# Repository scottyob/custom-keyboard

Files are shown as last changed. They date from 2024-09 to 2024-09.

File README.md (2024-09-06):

# custom-keyboard
My very first custom keyboard!

## Goals
* Be really quick to change machines from a work computer, personal computer, and embedded computer
* Have an embeded display for e-mails and custom notifications.

## Designing
[Keyboard Layout Editor](http://www.keyboard-layout-editor.com/) is used to build the layout
[PCB Generator](https://builder.mrkeebs.com/) is used to build the base KiCad templates - Not working
[KiCad plugin](https://github.com/adamws/kicad-kbplacer) Maybe this

## Inspiration
https://github.com/overlordpro-sys/keycool84keyboard
[Designers Guide](https://wiki.ai03.com/books/pcb-design/chapter/pcb-designer-guide)
[Great YouTube Design](https://www.youtube.com/watch?v=8WXpGTIbxlQ) (plus, his name is Scotto!)

## Display options
* This looks small enough and has a large enough resolution to be useful:  https://www.amazon.com/Portable-Computer-Temperature-Raspberry-Monitoring/dp/B0C5CJSM3B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

## Log
The KeyCool 84 model was used

## BOM
Keys:  https://www.amazon.com/Ranked-Ks-33-Switches-Mechanical-Keyboards/dp/B09WYFZ9RW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

Switches:  Keychron Low-Profile Keychron Optical White Switch Set:  https://www.amazon.com/Keychron-Low-Profile-Optical-White-Switch/dp/B09F8N5671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

---
Keys:  https://nuphy.com/products/nuphy-wisteria-t55-low-profile-switches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

[200~NuPhy Wisteria Low-profile Switches

**You'll want Gateron KS-33**

Use These:  https://shop.beekeeb.com/product/gateron-low-profile-hotswap-socket/
With this footprint:  https://github.com/siderakb/key-switches.pretty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

Guides:
https://github.com/ebastler/zmk-designguide
this recommends holyiot 18010 or moko mk08a. other people fiddle around with stuff like xiao nrf or even nice!nano (or nice!nano clones)

Keycaps perhaps:
- These are not shine through, but I like them!  https://www.amazon.com/Chocfox-Keyboard-Switches-Mechanical-white-134Keys/dp/B0CQ1ZHDP8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

- Yeah, I think these keycaps:  https://www.amazon.com/XVX-Profile-Keyboard-Switches-Mechanical/dp/B0BVYV67QS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

 - Controller

Probably this:  https://makerdiary.com/products/nrf52840-connectkit?variant=43255093035163

# Setup
1. Install [This Plugin](https://github.com/ebastler/marbastlib)
2. 

Footprint for KS-33:  https://shop.beekeeb.com/product/gateron-low-profile-hotswap-socket/

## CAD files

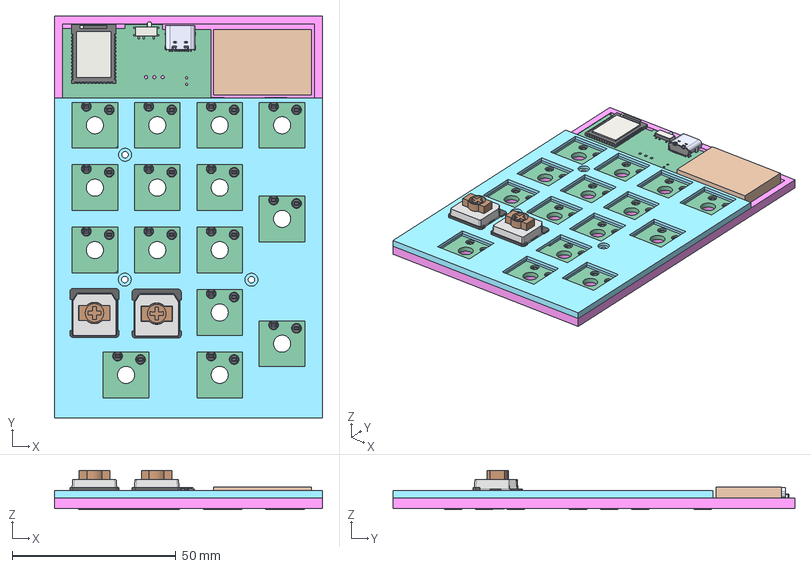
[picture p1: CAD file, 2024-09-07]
Schema/Keypad/Enclosure.FCStd
81.9 x 122.7 x 11.9 mm
f0684a6a-028c-11ee-ae0e-34c93d8226b1_part
f06a1f0c-028c-11ee-ae0e-34c93d8226b1_part
f1cc5b76-028c-11ee-ae0e-34c93d8226b1_part
f1cc5d06-028c-11ee-ae0e-34c93d8226b1_part
f1cc5d92-028c-11ee-ae0e-34c93d8226b1_part
f1cc5d92-028c-11ee-ae0e-34c93d8226b1_part001
f0684a6a-028c-11ee-ae0e-34c93d8226b1_part001
f06a1f0c-028c-11ee-ae0e-34c93d8226b1_part001
f1cc5b76-028c-11ee-ae0e-34c93d8226b1_part001
f1cc5d06-028c-11ee-ae0e-34c93d8226b1_part001
f1cc5d92-028c-11ee-ae0e-34c93d8226b1_part003
f1cc5d92-028c-11ee-ae0e-34c93d8226b1_part004
Pcb_ee0a
TYPE-C-31-M-12
TYPE-C-31-M-013
TYPE-C-31-M-014
TYPE-C-31-M-015
TYPE-C-31-M-016
TYPE-C-31-M-017
TYPE-C-31-M-018
TYPE-C-31-M-019
TYPE-C-31-M-020
TYPE-C-31-M-021
TYPE-C-31-M-022
TYPE-C-31-M-023
TYPE-C-31-M-024
TYPE-C-31-M-025
TYPE-C-31-M-026
TYPE-C-31-M-027
TYPE-C-31-M-028
TYPE-C-31-M-029
TYPE-C-31-M-030
TYPE-C-31-M-031
TYPE-C-31-M-032
TYPE-C-31-M-033
TYPE-C-31-M-034
TYPE-C-31-M-035
TYPE-C-31-M-036
TYPE-C-31-M-037
TYPE-C-31-M-038
TYPE-C-31-M-039
TYPE-C-31-M-040
TYPE-C-31-M-041
TYPE-C-31-M-042
TYPE-C-31-M-043
TYPE-C-31-M-044
TYPE-C-31-M-045
TYPE-C-31-M-046
TYPE-C-31-M-047
TYPE-C-31-M-048
TYPE-C-31-M-049
TYPE-C-31-M-050
TYPE-C-31-M-051
TYPE-C-31-M-052
TYPE-C-31-M-053
MSK12C02 v4
MSK12C02 v005
MSK12C02 v006
MSK12C02 v007
MSK12C02 v008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

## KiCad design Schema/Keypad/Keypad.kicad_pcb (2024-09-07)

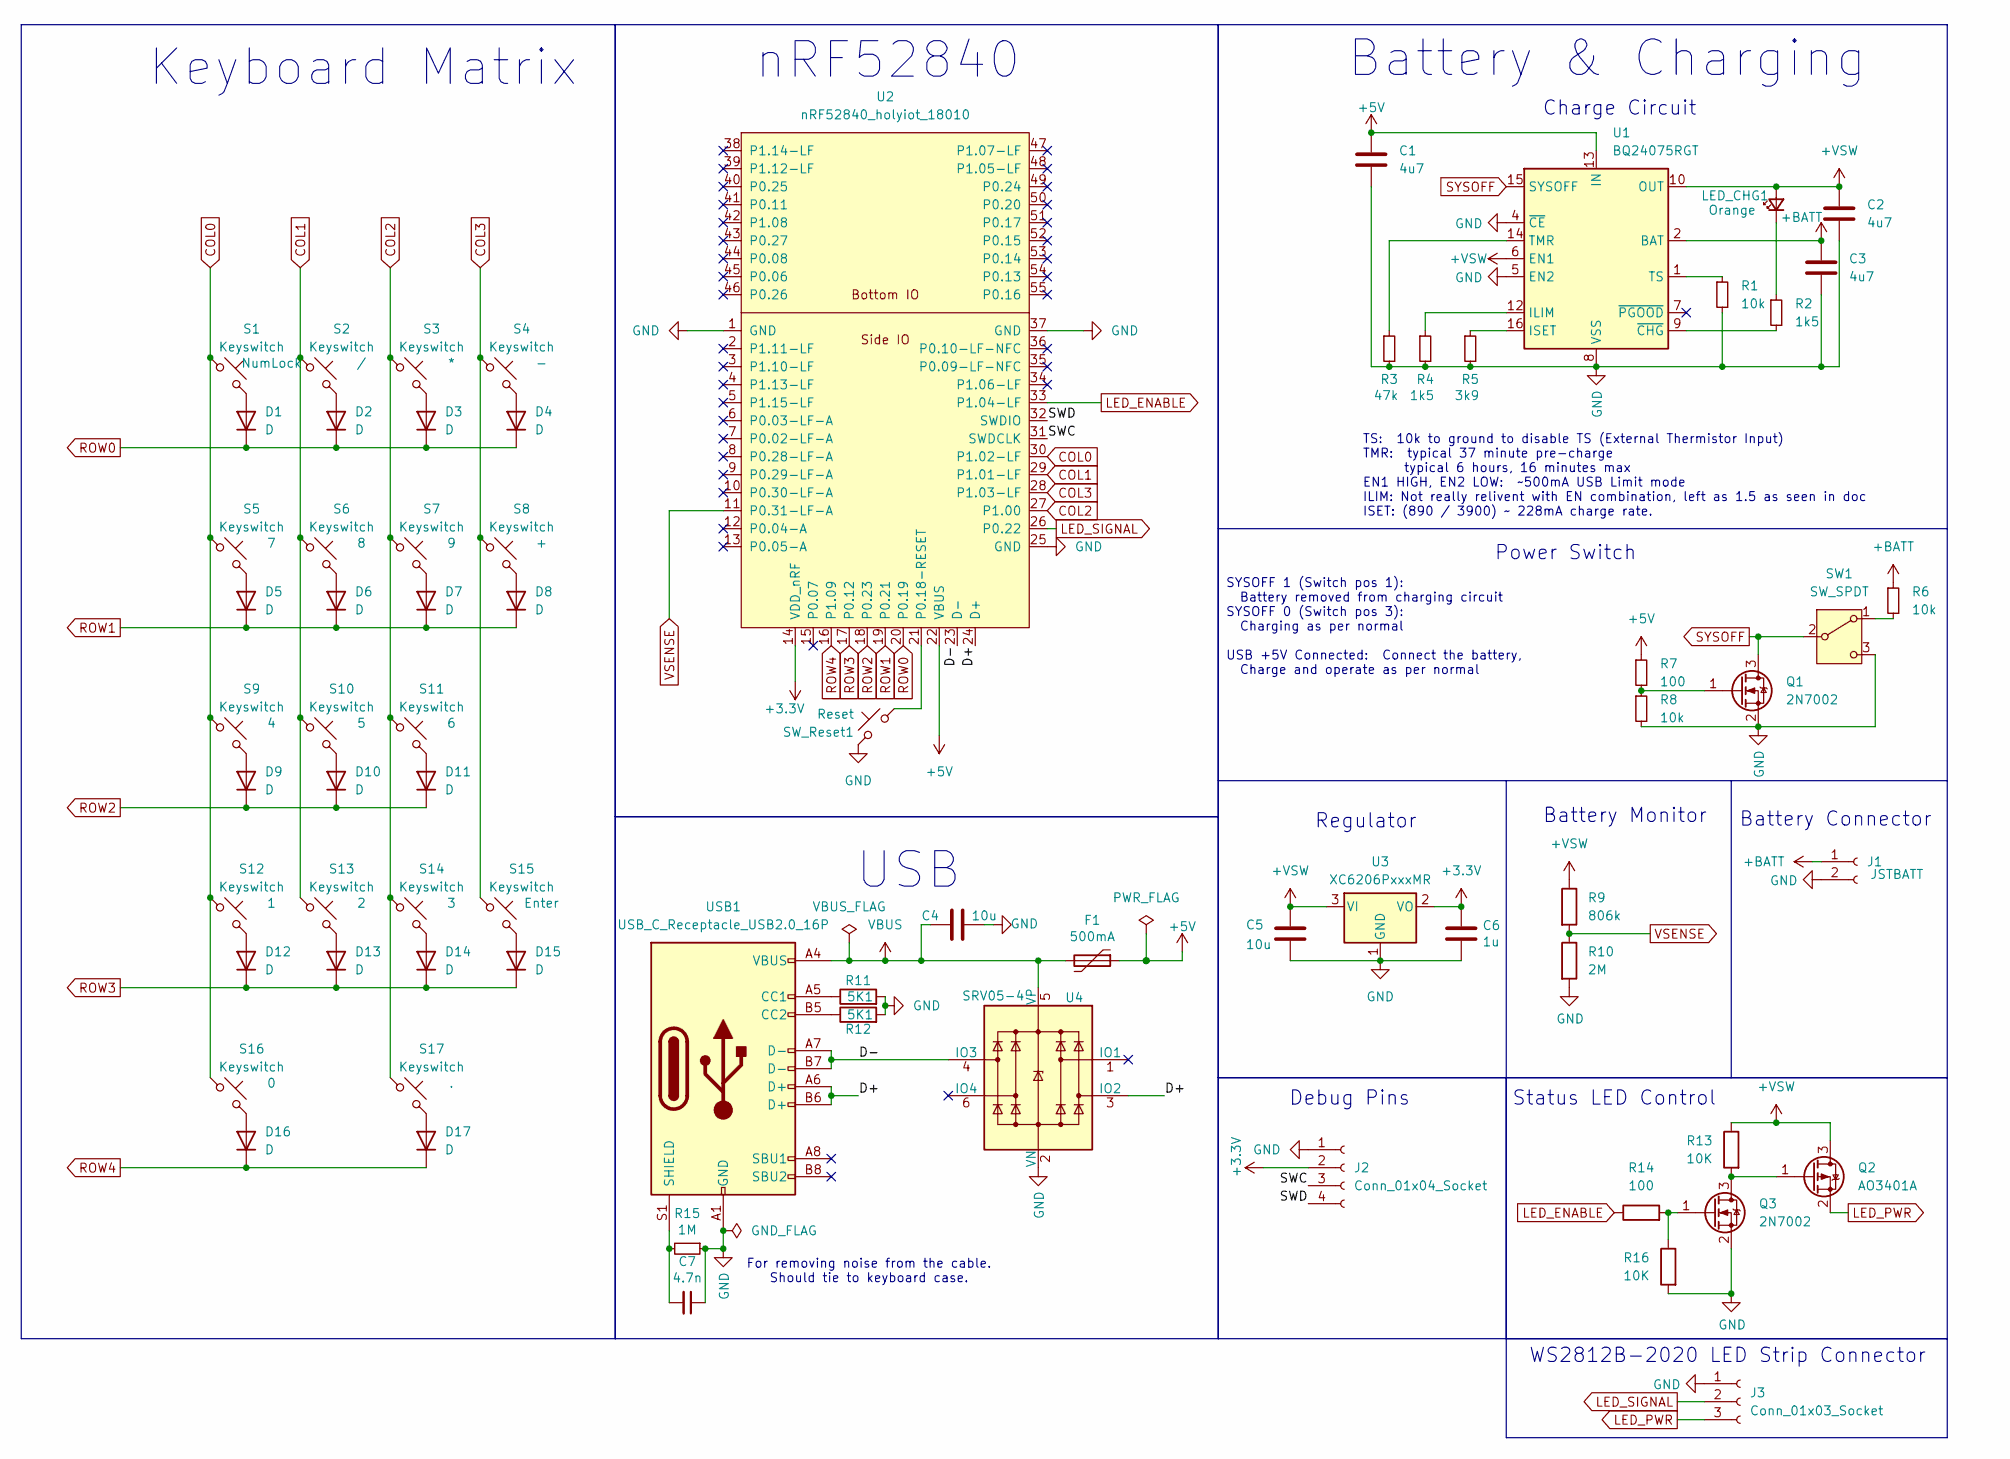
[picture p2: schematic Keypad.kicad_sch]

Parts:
C1, C2, C3: 4u7; C_0603_1608Metric
C4, C5: 10u; C_0603_1608Metric; MPN CL10A106KP8NNNC; JLCSMT C19702
C6: 1u; C_0603_1608Metric; MPN CL10A105KB8NNNC; LCSC C15849
C7: 4.7n; C_0805_2012Metric
D1, D2, D3, D4, D5, D6, D7, D8, D9, D10, D11, D12, D13, D14, D15, D16, D17: D; Diode_SOD-123
F1: 500mA; Fuse_0805_2012Metric; MPN SMD0805-050; JLCSMT C66452
J1: JSTBATT; JST_PH_S2B-PH-K_1x02_P2.00mm_Horizontal
J2: Conn_01x04_Socket; PinHeader_1x04_P2.54mm_Vertical
J3: Conn_01x03_Socket; PinSocket_1x03_P2.54mm_Vertical
LED_CHG1: Orange; LED_0603_1608Metric_Pad1.05x0.95mm_HandSolder
Q1, Q3: 2N7002; SOT-23
Q2: AO3401A; SOT-23
R1, R6, R8: 10k; R_0603_1608Metric_Pad0.98x0.95mm_HandSolder
R2, R4: 1k5; R_0603_1608Metric_Pad0.98x0.95mm_HandSolder
R3: 47k; R_0603_1608Metric_Pad0.98x0.95mm_HandSolder
R5: 3k9; R_0603_1608Metric_Pad0.98x0.95mm_HandSolder
R7, R14: 100; R_0603_1608Metric_Pad0.98x0.95mm_HandSolder
R9: 806k; R_0603_1608Metric_Pad0.98x0.95mm_HandSolder
R10: 2M; R_0603_1608Metric_Pad0.98x0.95mm_HandSolder
R11, R12: 5K1; R_0603_1608Metric_Pad0.98x0.95mm_HandSolder
R13, R16: 10K; R_0603_1608Metric_Pad0.98x0.95mm_HandSolder
R15: 1M; R_0603_1608Metric_Pad0.98x0.95mm_HandSolder
S1, S2, S3, S4, S5, S6, S7, S8, S9, S10, S11, S12, S13, S14, S15, S16, S17: Keyswitch; SW_KS33_HS_KS-2P02B01-02_HS_1u
SW1: SW_SPDT; SW_MSK12C02-HB
SW_Reset1: Reset; SW_Push_1P1T_NO_6x6mm_H9.5mm
U1: BQ24075RGT; VQFN-16-1EP_3x3mm_P0.5mm_EP1.6x1.6mm
U2: nRF52840_holyiot_18010
U3: XC6206PxxxMR; SOT-23-3
U4: SRV05-4; SOT-23-6; MPN SRV05-4-P-T7; JLCSMT C85364
USB1: USB_C_Receptacle_USB2.0_16P; USB_C_Receptacle_HRO_TYPE-C-31-M-12

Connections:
+3.3V: C6.2, J2.2, U2.14 (VDD_nRF), U3.2 (VO)
+5V: C1.1, F1.1, R7.1, U1.13 (IN), U2.22 (VBUS)
+BATT: C3.1, J1.1, R6.1, U1.2 (BAT), U1.3 (BAT)
+VSW: C2.1, C5.1, LED_CHG1.2 (A), Q2.3 (D), R9.1, R13.1, U1.6 (EN1), U1.10 (OUT), U1.11 (OUT), U3.3 (VI)
/D+: U2.24 (D+), U4.3 (IO2), USB1.A6 (D+), USB1.B6 (D+)
/D-: U2.23 (D-), U4.4 (IO3), USB1.A7 (D-), USB1.B7 (D-)
/SWC: J2.3, U2.31 (SWDCLK)
/SWD: J2.4, U2.32 (SWDIO)
COL0: S1.1, S5.1, S9.1, S12.1, S16.1, U2.30 (P1.02-LF)
COL1: S2.1, S6.1, S10.1, S13.1, U2.29 (P1.01-LF)
COL2: S3.1, S7.1, S11.1, S14.1, S17.1, U2.27 (P1.00)
COL3: S4.1, S8.1, S15.1, U2.28 (P1.03-LF)
GND: C1.2, C2.2, C3.2, C4.1, C5.2, C6.1, C7.1, J1.2, J2.1, J3.1, Q1.2 (S), Q3.2 (S), R1.2, R3.2, R4.2, R5.2, R8.2, R10.2, R11.2, R12.2, R15.1, R16.2, SW1.3 (C), SW_Reset1.1, U1.4 (~CE), U1.5 (EN2), U1.8 (VSS), U1.17 (VSS), U2.1 (GND), U2.25 (GND), U2.37 (GND), U3.1 (GND), U4.2 (VN), USB1.A1 (GND), USB1.A12 (GND), USB1.B1 (GND), USB1.B12 (GND)
LED_ENABLE: R14.1, U2.33 (P1.04-LF)
LED_PWR: J3.3, Q2.2 (S)
LED_SIGNAL: J3.2, U2.26 (P0.22)
unnamed: D1.2 (A), S1.2
unnamed: D2.2 (A), S2.2
unnamed: D3.2 (A), S3.2
unnamed: D4.2 (A), S4.2
unnamed: D5.2 (A), S5.2
unnamed: D6.2 (A), S6.2
unnamed: D7.2 (A), S7.2
unnamed: D8.2 (A), S8.2
unnamed: D9.2 (A), S9.2
unnamed: D10.2 (A), S10.2
unnamed: D11.2 (A), S11.2
unnamed: D12.2 (A), S12.2
unnamed: D13.2 (A), S13.2
unnamed: D14.2 (A), S14.2
unnamed: D15.2 (A), S15.2
unnamed: D16.2 (A), S16.2
unnamed: D17.2 (A), S17.2
unnamed: LED_CHG1.1 (K), R2.1
unnamed: Q1.1 (G), R7.2, R8.1
unnamed: Q2.1 (G), Q3.3 (D), R13.2
unnamed: Q3.1 (G), R14.2, R16.1
unnamed: R6.2, SW1.1 (A)
unnamed: R4.1, U1.12 (ILIM)
unnamed: R5.1, U1.16 (ISET)
unnamed: R3.1, U1.14 (TMR)
unnamed: R1.1, U1.1 (TS)
unnamed: R2.2, U1.9 (~CHG)
unnamed: SW_Reset1.2, U2.21 (P0.18-RESET)
unnamed: R11.1, USB1.A5 (CC1)
unnamed: R12.1, USB1.B5 (CC2)
unnamed: C7.2, R15.2, USB1.S1 (SHIELD)
ROW0: D1.1 (K), D2.1 (K), D3.1 (K), D4.1 (K), U2.20 (P0.19)
ROW1: D5.1 (K), D6.1 (K), D7.1 (K), D8.1 (K), U2.19 (P0.21)
ROW2: D9.1 (K), D10.1 (K), D11.1 (K), U2.18 (P0.23)
ROW3: D12.1 (K), D13.1 (K), D14.1 (K), D15.1 (K), U2.17 (P0.12)
ROW4: D16.1 (K), D17.1 (K), U2.16 (P1.09)
SYSOFF: Q1.3 (D), SW1.2 (B), U1.15 (SYSOFF)
VBUS: C4.2, F1.2, U4.5 (VP), USB1.A4 (VBUS), USB1.A9 (VBUS), USB1.B4 (VBUS), USB1.B9 (VBUS)
VSENSE: R9.2, R10.1, U2.11 (P0.31-LF-A)

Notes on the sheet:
Status LED Control
WS2812B-2020 LED Strip Connector
USB
Battery & Charging
nRF52840
Charge Circuit
Battery Connector
Power Switch
Keyboard Matrix
SYSOFF 1 (Switch pos 1): Battery removed from charging circuit SYSOFF 0 (Switch pos 3): Charging as per normal USB +5V Connected: Connect the battery, Charge and operate as per normal
Debug Pins
For removing noise from the cable. Should tie to keyboard case.
Battery Monitor
Regulator
TS: 10k to ground to disable TS (External Thermistor Input) TMR: typical 37 minute pre-charge typical 6 hours, 16 minutes max EN1 HIGH, EN2 LOW: ~500mA USB Limit mode ILIM: Not really relivent with EN combination, left as 1.5 as seen in doc ISET: (890 / 3900) ~ 228mA charge rate.

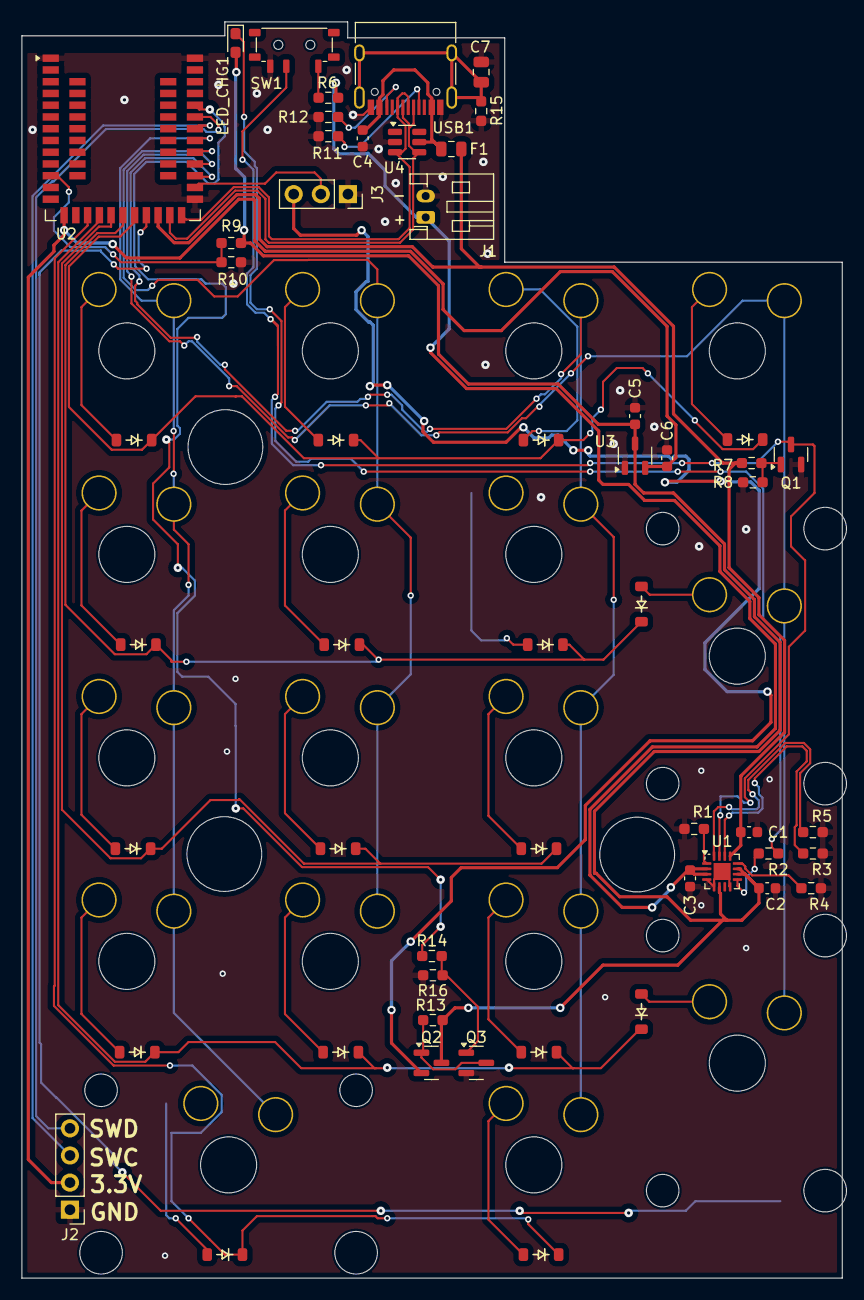
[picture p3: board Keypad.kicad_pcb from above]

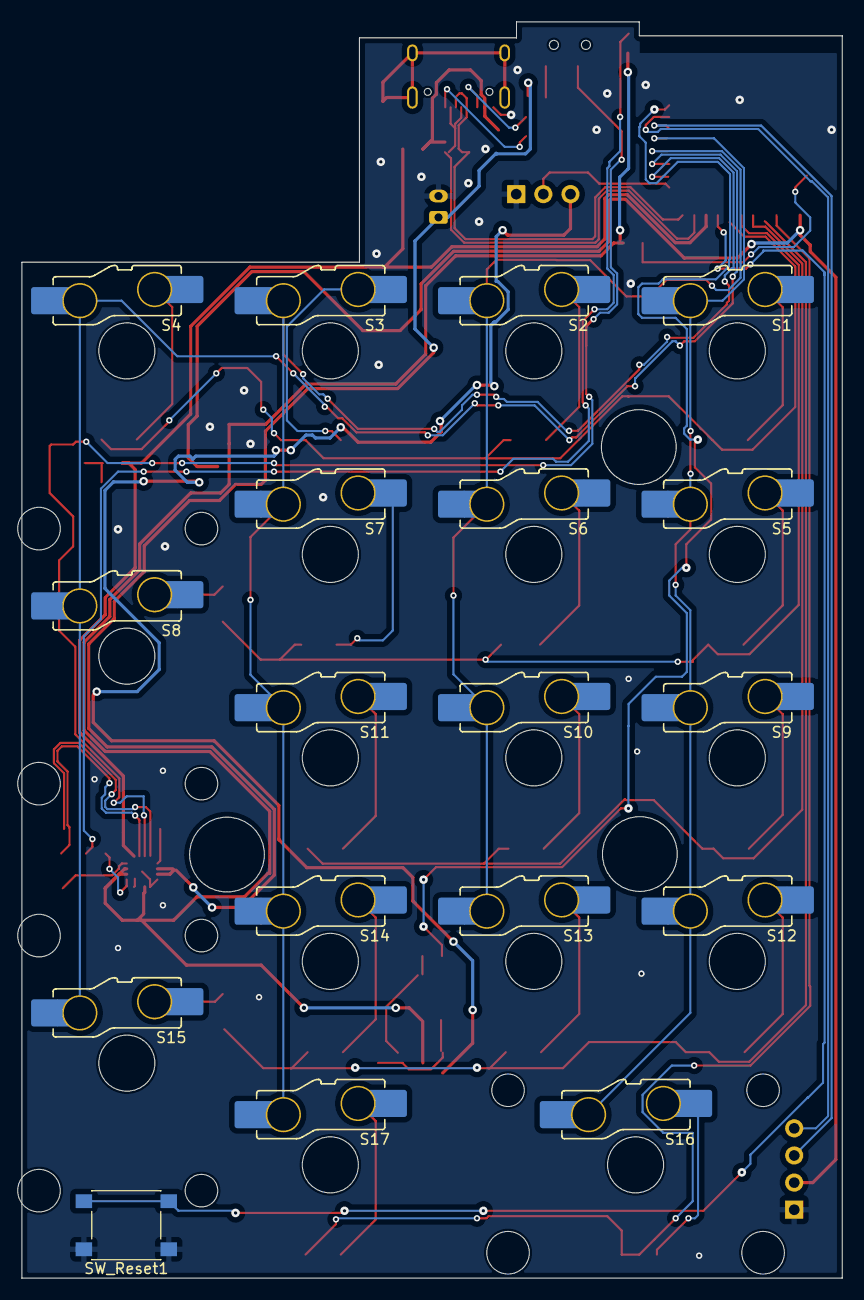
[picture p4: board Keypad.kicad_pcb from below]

Board: 2 copper layers, 76.8 x 117.6 mm, 72 parts (18 on the bottom side), 55 nets.

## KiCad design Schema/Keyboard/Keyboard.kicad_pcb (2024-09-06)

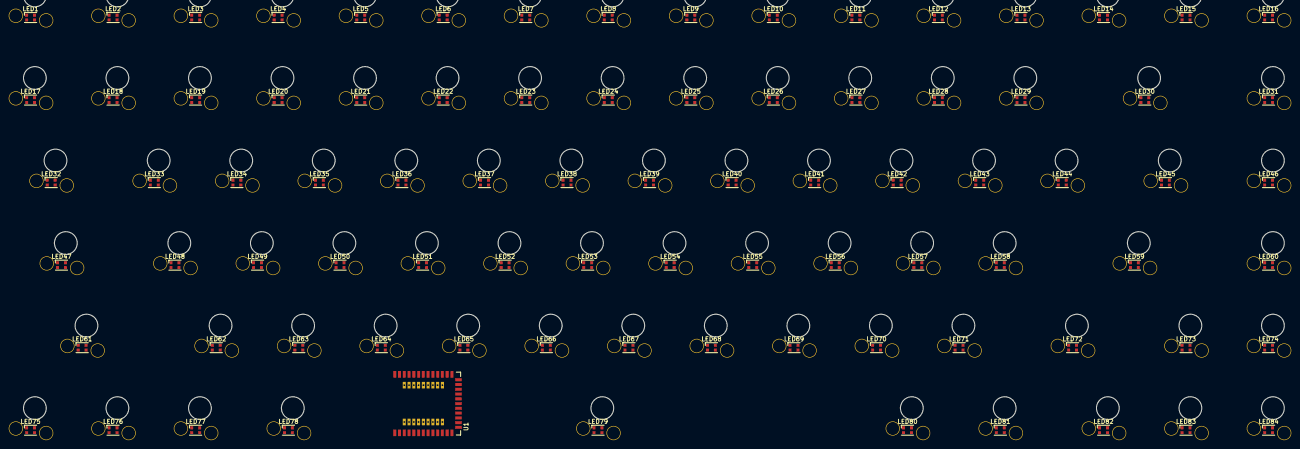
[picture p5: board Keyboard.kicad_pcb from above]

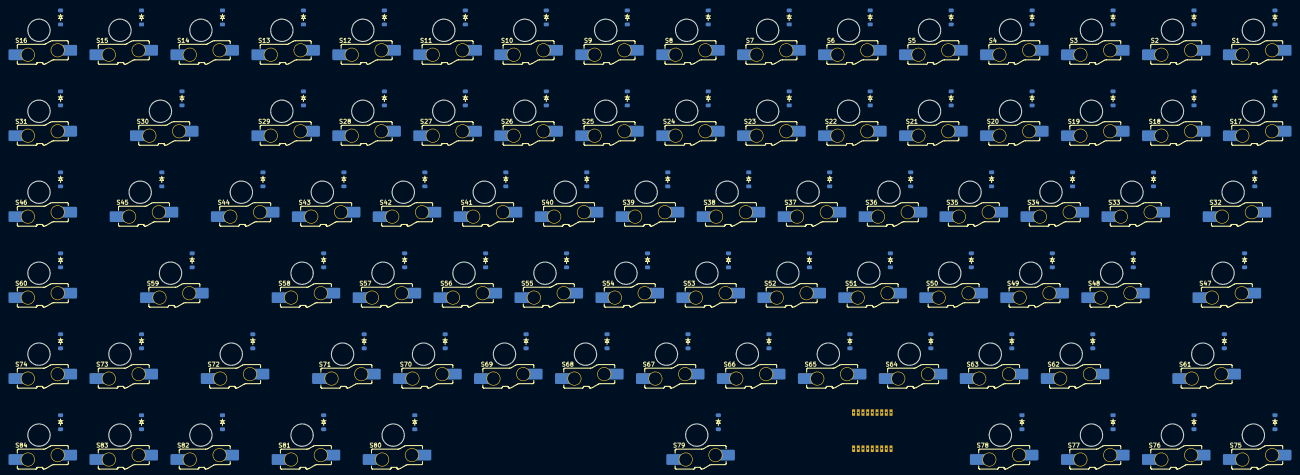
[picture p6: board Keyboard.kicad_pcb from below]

Board: 2 copper layers, 253 parts (168 on the bottom side), 191 nets, no tracks yet.

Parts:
D1, D2, D3, D4, D5, D6, D7, D8, D9, D10, D11, D12, D13, D14, D15, D16, D17, D18, D19, D20, D21, D22, D23, D24, D25, D26, D27, D28, D29, D30, D31, D32, D33, D34, D35, D36, D37, D38, D39, D40, D41, D42, D43, D44, D45, D46, D47, D48, D49, D50, D51, D52, D53, D54, D55, D56, D57, D58, D59, D60, D61, D62, D63, D64, D65, D66, D67, D68, D69, D70, D71, D72, D73, D74, D75, D76, D77, D78, D79, D80, D81, D82, D83, D84: D; Diode_SOD-123
LED1, LED2, LED3, LED4, LED5, LED6, LED7, LED8, LED9, LED10, LED11, LED12, LED13, LED14, LED15, LED16, LED17, LED18, LED19, LED20, LED21, LED22, LED23, LED24, LED25, LED26, LED27, LED28, LED29, LED30, LED31, LED32, LED33, LED34, LED35, LED36, LED37, LED38, LED39, LED40, LED41, LED42, LED43, LED44, LED45, LED46, LED47, LED48, LED49, LED50, LED51, LED52, LED53, LED54, LED55, LED56, LED57, LED58, LED59, LED60, LED61, LED62, LED63, LED64, LED65, LED66, LED67, LED68, LED69, LED70, LED71, LED72, LED73, LED74, LED75, LED76, LED77, LED78, LED79, LED80, LED81, LED82, LED83, LED84: WS2812B-2020; LED_WS2812B-2020_PLCC4_2.0x2.0mm
S1, S2, S3, S4, S5, S6, S7, S8, S9, S10, S11, S12, S13, S14, S15, S16, S17, S18, S19, S20, S21, S22, S23, S24, S25, S26, S27, S28, S29, S30, S31, S32, S33, S34, S35, S36, S37, S38, S39, S40, S41, S42, S43, S44, S45, S46, S47, S48, S49, S50, S51, S52, S53, S54, S55, S56, S57, S58, S59, S60, S61, S62, S63, S64, S65, S66, S67, S68, S69, S70, S71, S72, S73, S74, S75, S76, S77, S78, S79, S80, S81, S82, S83, S84: Keyswitch; SW_KS33_HS_KS-2P02B01-02_HS_1u
U1: nRF52840_holyiot_18010

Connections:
+5V: LED1.4 (VDD), LED2.4 (VDD), LED3.4 (VDD), LED4.4 (VDD), LED5.4 (VDD), LED6.4 (VDD), LED7.4 (VDD), LED8.4 (VDD), LED9.4 (VDD), LED10.4 (VDD), LED11.4 (VDD), LED12.4 (VDD), LED13.4 (VDD), LED14.4 (VDD), LED15.4 (VDD), LED16.4 (VDD), LED17.4 (VDD), LED18.4 (VDD), LED19.4 (VDD), LED20.4 (VDD), LED21.4 (VDD), LED22.4 (VDD), LED23.4 (VDD), LED24.4 (VDD), LED25.4 (VDD), LED26.4 (VDD), LED27.4 (VDD), LED28.4 (VDD), LED29.4 (VDD), LED30.4 (VDD), LED31.4 (VDD), LED32.4 (VDD), LED33.4 (VDD), LED34.4 (VDD), LED35.4 (VDD), LED36.4 (VDD), LED37.4 (VDD), LED38.4 (VDD), LED39.4 (VDD), LED40.4 (VDD), LED41.4 (VDD), LED42.4 (VDD), LED43.4 (VDD), LED44.4 (VDD), LED45.4 (VDD), LED46.4 (VDD), LED47.4 (VDD), LED48.4 (VDD), LED49.4 (VDD), LED50.4 (VDD), LED51.4 (VDD), LED52.4 (VDD), LED53.4 (VDD), LED54.4 (VDD), LED55.4 (VDD), LED56.4 (VDD), LED57.4 (VDD), LED58.4 (VDD), LED59.4 (VDD), LED60.4 (VDD), LED61.4 (VDD), LED62.4 (VDD), LED63.4 (VDD), LED64.4 (VDD), LED65.4 (VDD), LED66.4 (VDD), LED67.4 (VDD), LED68.4 (VDD), LED69.4 (VDD), LED70.4 (VDD), LED71.4 (VDD), LED72.4 (VDD), LED73.4 (VDD), LED74.4 (VDD), LED75.4 (VDD), LED76.4 (VDD), LED77.4 (VDD), LED78.4 (VDD), LED79.4 (VDD), LED80.4 (VDD), LED81.4 (VDD), LED82.4 (VDD), LED83.4 (VDD), LED84.4 (VDD)
COL0: S1.1, S17.1, S32.1, S47.1, S75.1
COL1: S2.1, S18.1, S61.1, S76.1
COL2: S3.1, S19.1, S33.1, S48.1, S62.1, S77.1
COL3: S4.1, S20.1, S34.1, S49.1, S63.1, S78.1
COL4: S5.1, S21.1, S35.1, S50.1, S64.1
COL5: S6.1, S22.1, S36.1, S51.1, S65.1
COL6: S7.1, S23.1, S37.1, S52.1, S66.1, S79.1
COL7: S8.1, S24.1, S38.1, S53.1, S67.1
COL8: S9.1, S25.1, S39.1, S54.1, S68.1
COL9: S10.1, S26.1, S40.1, S55.1, S69.1
COL10: S11.1, S27.1, S41.1, S56.1, S70.1, S80.1
COL11: S12.1, S28.1, S42.1, S57.1, S71.1, S81.1
COL12: S13.1, S29.1, S43.1, S58.1
COL13: S14.1, S44.1, S59.1, S72.1, S82.1
COL14: S15.1, S30.1, S45.1, S73.1, S83.1
COL15: S16.1, S31.1, S46.1, S60.1, S74.1, S84.1
GND: LED1.2 (VSS), LED2.2 (VSS), LED3.2 (VSS), LED4.2 (VSS), LED5.2 (VSS), LED6.2 (VSS), LED7.2 (VSS), LED8.2 (VSS), LED9.2 (VSS), LED10.2 (VSS), LED11.2 (VSS), LED12.2 (VSS), LED13.2 (VSS), LED14.2 (VSS), LED15.2 (VSS), LED16.2 (VSS), LED17.2 (VSS), LED18.2 (VSS), LED19.2 (VSS), LED20.2 (VSS), LED21.2 (VSS), LED22.2 (VSS), LED23.2 (VSS), LED24.2 (VSS), LED25.2 (VSS), LED26.2 (VSS), LED27.2 (VSS), LED28.2 (VSS), LED29.2 (VSS), LED30.2 (VSS), LED31.2 (VSS), LED32.2 (VSS), LED33.2 (VSS), LED34.2 (VSS), LED35.2 (VSS), LED36.2 (VSS), LED37.2 (VSS), LED38.2 (VSS), LED39.2 (VSS), LED40.2 (VSS), LED41.2 (VSS), LED42.2 (VSS), LED43.2 (VSS), LED44.2 (VSS), LED45.2 (VSS), LED46.2 (VSS), LED47.2 (VSS), LED48.2 (VSS), LED49.2 (VSS), LED50.2 (VSS), LED51.2 (VSS), LED52.2 (VSS), LED53.2 (VSS), LED54.2 (VSS), LED55.2 (VSS), LED56.2 (VSS), LED57.2 (VSS), LED58.2 (VSS), LED59.2 (VSS), LED60.2 (VSS), LED61.2 (VSS), LED62.2 (VSS), LED63.2 (VSS), LED64.2 (VSS), LED65.2 (VSS), LED66.2 (VSS), LED67.2 (VSS), LED68.2 (VSS), LED69.2 (VSS), LED70.2 (VSS), LED71.2 (VSS), LED72.2 (VSS), LED73.2 (VSS), LED74.2 (VSS), LED75.2 (VSS), LED76.2 (VSS), LED77.2 (VSS), LED78.2 (VSS), LED79.2 (VSS), LED80.2 (VSS), LED81.2 (VSS), LED82.2 (VSS), LED83.2 (VSS), LED84.2 (VSS)
unnamed: D1.2 (A), S1.2
unnamed: D2.2 (A), S2.2
unnamed: D3.2 (A), S3.2
unnamed: D4.2 (A), S4.2
unnamed: D5.2 (A), S5.2
unnamed: D6.2 (A), S6.2
unnamed: D7.2 (A), S7.2
unnamed: D8.2 (A), S8.2
unnamed: D9.2 (A), S9.2
unnamed: D10.2 (A), S10.2
unnamed: D11.2 (A), S11.2
unnamed: D12.2 (A), S12.2
unnamed: D13.2 (A), S13.2
unnamed: D14.2 (A), S14.2
unnamed: D15.2 (A), S15.2
unnamed: D16.2 (A), S16.2
unnamed: D17.2 (A), S17.2
unnamed: D18.2 (A), S18.2
unnamed: D19.2 (A), S19.2
unnamed: D20.2 (A), S20.2
unnamed: D21.2 (A), S21.2
unnamed: D22.2 (A), S22.2
unnamed: D23.2 (A), S23.2
unnamed: D24.2 (A), S24.2
unnamed: D25.2 (A), S25.2
unnamed: D26.2 (A), S26.2
unnamed: D27.2 (A), S27.2
unnamed: D28.2 (A), S28.2
unnamed: D29.2 (A), S29.2
unnamed: D30.2 (A), S30.2
unnamed: D31.2 (A), S31.2
unnamed: D32.2 (A), S32.2
unnamed: D33.2 (A), S33.2
unnamed: D34.2 (A), S34.2
unnamed: D35.2 (A), S35.2
unnamed: D36.2 (A), S36.2
unnamed: D37.2 (A), S37.2
unnamed: D38.2 (A), S38.2
unnamed: D39.2 (A), S39.2
unnamed: D40.2 (A), S40.2
unnamed: D41.2 (A), S41.2
unnamed: D42.2 (A), S42.2
unnamed: D43.2 (A), S43.2
unnamed: D44.2 (A), S44.2
unnamed: D45.2 (A), S45.2
unnamed: D46.2 (A), S46.2
unnamed: D47.2 (A), S47.2
unnamed: D48.2 (A), S48.2
unnamed: D49.2 (A), S49.2
unnamed: D50.2 (A), S50.2
unnamed: D51.2 (A), S51.2
unnamed: D52.2 (A), S52.2
unnamed: D53.2 (A), S53.2
unnamed: D54.2 (A), S54.2
unnamed: D55.2 (A), S55.2
unnamed: D56.2 (A), S56.2
unnamed: D57.2 (A), S57.2
unnamed: D58.2 (A), S58.2
unnamed: D59.2 (A), S59.2
unnamed: D60.2 (A), S60.2
unnamed: D61.2 (A), S61.2
unnamed: D62.2 (A), S62.2
unnamed: D63.2 (A), S63.2
unnamed: D64.2 (A), S64.2
unnamed: D65.2 (A), S65.2
unnamed: D66.2 (A), S66.2
unnamed: D67.2 (A), S67.2
unnamed: D68.2 (A), S68.2
unnamed: D69.2 (A), S69.2
unnamed: D70.2 (A), S70.2
unnamed: D71.2 (A), S71.2
unnamed: D72.2 (A), S72.2
unnamed: D73.2 (A), S73.2
unnamed: D74.2 (A), S74.2
unnamed: D75.2 (A), S75.2
unnamed: D76.2 (A), S76.2
unnamed: D77.2 (A), S77.2
unnamed: D78.2 (A), S78.2
unnamed: D79.2 (A), S79.2
unnamed: D80.2 (A), S80.2
unnamed: D81.2 (A), S81.2
unnamed: D82.2 (A), S82.2
unnamed: D83.2 (A), S83.2
unnamed: D84.2 (A), S84.2
unnamed: LED1.1 (DOUT), LED2.3 (DIN)
unnamed: LED2.1 (DOUT), LED3.3 (DIN)
unnamed: LED3.1 (DOUT), LED4.3 (DIN)
unnamed: LED4.1 (DOUT), LED5.3 (DIN)
unnamed: LED5.1 (DOUT), LED6.3 (DIN)
unnamed: LED6.1 (DOUT), LED7.3 (DIN)
unnamed: LED7.1 (DOUT), LED8.3 (DIN)
unnamed: LED8.1 (DOUT), LED9.3 (DIN)
unnamed: LED9.1 (DOUT), LED10.3 (DIN)
unnamed: LED10.1 (DOUT), LED11.3 (DIN)
unnamed: LED11.1 (DOUT), LED12.3 (DIN)
unnamed: LED12.1 (DOUT), LED13.3 (DIN)
unnamed: LED13.1 (DOUT), LED14.3 (DIN)
unnamed: LED14.1 (DOUT), LED15.3 (DIN)
unnamed: LED15.1 (DOUT), LED16.3 (DIN)
unnamed: LED16.1 (DOUT), LED17.3 (DIN)
unnamed: LED17.1 (DOUT), LED18.3 (DIN)
unnamed: LED18.1 (DOUT), LED19.3 (DIN)
unnamed: LED19.1 (DOUT), LED20.3 (DIN)
unnamed: LED20.1 (DOUT), LED21.3 (DIN)
unnamed: LED21.1 (DOUT), LED22.3 (DIN)
unnamed: LED22.1 (DOUT), LED23.3 (DIN)
unnamed: LED23.1 (DOUT), LED24.3 (DIN)
unnamed: LED24.1 (DOUT), LED25.3 (DIN)
unnamed: LED25.1 (DOUT), LED26.3 (DIN)
unnamed: LED26.1 (DOUT), LED27.3 (DIN)
unnamed: LED27.1 (DOUT), LED28.3 (DIN)
unnamed: LED28.1 (DOUT), LED29.3 (DIN)
unnamed: LED29.1 (DOUT), LED30.3 (DIN)
unnamed: LED30.1 (DOUT), LED31.3 (DIN)
unnamed: LED31.1 (DOUT), LED32.3 (DIN)
unnamed: LED32.1 (DOUT), LED33.3 (DIN)
unnamed: LED33.1 (DOUT), LED34.3 (DIN)
unnamed: LED34.1 (DOUT), LED35.3 (DIN)
unnamed: LED35.1 (DOUT), LED36.3 (DIN)
unnamed: LED36.1 (DOUT), LED37.3 (DIN)
unnamed: LED37.1 (DOUT), LED38.3 (DIN)
unnamed: LED38.1 (DOUT), LED39.3 (DIN)
unnamed: LED39.1 (DOUT), LED40.3 (DIN)
unnamed: LED40.1 (DOUT), LED41.3 (DIN)
unnamed: LED41.1 (DOUT), LED42.3 (DIN)
unnamed: LED42.1 (DOUT), LED43.3 (DIN)
unnamed: LED43.1 (DOUT), LED44.3 (DIN)
unnamed: LED44.1 (DOUT), LED45.3 (DIN)
unnamed: LED45.1 (DOUT), LED46.3 (DIN)
unnamed: LED46.1 (DOUT), LED47.3 (DIN)
unnamed: LED47.1 (DOUT), LED48.3 (DIN)
unnamed: LED48.1 (DOUT), LED49.3 (DIN)
unnamed: LED49.1 (DOUT), LED50.3 (DIN)
unnamed: LED50.1 (DOUT), LED51.3 (DIN)
unnamed: LED51.1 (DOUT), LED52.3 (DIN)
unnamed: LED52.1 (DOUT), LED53.3 (DIN)
unnamed: LED53.1 (DOUT), LED54.3 (DIN)
unnamed: LED54.1 (DOUT), LED55.3 (DIN)
unnamed: LED55.1 (DOUT), LED56.3 (DIN)
unnamed: LED56.1 (DOUT), LED57.3 (DIN)
unnamed: LED57.1 (DOUT), LED58.3 (DIN)
unnamed: LED58.1 (DOUT), LED59.3 (DIN)
unnamed: LED59.1 (DOUT), LED60.3 (DIN)
unnamed: LED60.1 (DOUT), LED61.3 (DIN)
unnamed: LED61.1 (DOUT), LED62.3 (DIN)
unnamed: LED62.1 (DOUT), LED63.3 (DIN)
unnamed: LED63.1 (DOUT), LED64.3 (DIN)
unnamed: LED64.1 (DOUT), LED65.3 (DIN)
unnamed: LED65.1 (DOUT), LED66.3 (DIN)
unnamed: LED66.1 (DOUT), LED67.3 (DIN)
unnamed: LED67.1 (DOUT), LED68.3 (DIN)
unnamed: LED68.1 (DOUT), LED69.3 (DIN)
unnamed: LED69.1 (DOUT), LED70.3 (DIN)
unnamed: LED70.1 (DOUT), LED71.3 (DIN)
unnamed: LED71.1 (DOUT), LED72.3 (DIN)
unnamed: LED72.1 (DOUT), LED73.3 (DIN)
unnamed: LED73.1 (DOUT), LED74.3 (DIN)
unnamed: LED74.1 (DOUT), LED75.3 (DIN)
unnamed: LED75.1 (DOUT), LED76.3 (DIN)
unnamed: LED76.1 (DOUT), LED77.3 (DIN)
unnamed: LED77.1 (DOUT), LED78.3 (DIN)
unnamed: LED78.1 (DOUT), LED79.3 (DIN)
unnamed: LED79.1 (DOUT), LED80.3 (DIN)
unnamed: LED80.1 (DOUT), LED81.3 (DIN)
unnamed: LED81.1 (DOUT), LED82.3 (DIN)
unnamed: LED82.1 (DOUT), LED83.3 (DIN)
unnamed: LED83.1 (DOUT), LED84.3 (DIN)
ROW0: D1.1 (K), D2.1 (K), D3.1 (K), D4.1 (K), D5.1 (K), D6.1 (K), D7.1 (K), D8.1 (K), D9.1 (K), D10.1 (K), D11.1 (K), D12.1 (K), D13.1 (K), D14.1 (K), D15.1 (K), D16.1 (K)
ROW1: D17.1 (K), D18.1 (K), D19.1 (K), D20.1 (K), D21.1 (K), D22.1 (K), D23.1 (K), D24.1 (K), D25.1 (K), D26.1 (K), D27.1 (K), D28.1 (K), D29.1 (K), D30.1 (K), D31.1 (K)
ROW2: D32.1 (K), D33.1 (K), D34.1 (K), D35.1 (K), D36.1 (K), D37.1 (K), D38.1 (K), D39.1 (K), D40.1 (K), D41.1 (K), D42.1 (K), D43.1 (K), D44.1 (K), D45.1 (K), D46.1 (K)
ROW3: D47.1 (K), D48.1 (K), D49.1 (K), D50.1 (K), D51.1 (K), D52.1 (K), D53.1 (K), D54.1 (K), D55.1 (K), D56.1 (K), D57.1 (K), D58.1 (K), D59.1 (K), D60.1 (K)
ROW4: D61.1 (K), D62.1 (K), D63.1 (K), D64.1 (K), D65.1 (K), D66.1 (K), D67.1 (K), D68.1 (K), D69.1 (K), D70.1 (K), D71.1 (K), D72.1 (K), D73.1 (K), D74.1 (K)
ROW5: D75.1 (K), D76.1 (K), D77.1 (K), D78.1 (K), D79.1 (K), D80.1 (K), D81.1 (K), D82.1 (K), D83.1 (K), D84.1 (K)

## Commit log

2024-09-06 Updating Schema
    [Enclosure.FCStd, Keyboard.kicad_pcb, Keyboard.kicad_sch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]
2024-09-07 Updating with enclosure
    [Enclosure.FCStd, Keypad.kicad_pcb, Keypad.kicad_sch]
